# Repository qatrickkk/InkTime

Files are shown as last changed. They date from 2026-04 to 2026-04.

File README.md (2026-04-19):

# InkTime Smartwatch

InkTime is a custom, open source smartwatch based on Nordic nRF52840, designed to have a low power consumption. It features an E-Ink display, 3-axis accelerometer, haptic feedback, and a 3 button navigation system.

## System Architecture Diagram
```mermaid
flowchart LR
    subgraph PWR["Power Subsystem"]
        USB["USB-C"]
        CHG["BQ25180<br/>Li-Ion Charger / Power Path"]
        BAT["AKY0106<br/>Li-Po Battery"]
        FG["MAX17048<br/>Fuel Gauge"]
        REG["RT6160<br/>Buck-Boost 3.3 V"]
        EPDPWR["E-Paper Drive Circuit<br/>(boost / gate / HV rails)"]
    end

    subgraph CTRL["Main Control"]
        MCU["nRF52840"]
    end

    subgraph PERI["Peripherals"]
        EPD["WSH-12561<br/>E-Ink Display"]
        IMU["BMA423 IMU"]
        HAPTIC["DRV2605<br/>Haptic Driver"]
        MOTOR["FIT0774<br/>Vibration Motor"]
        BTN["3 Physical Buttons<br/>(UP / ENTER / DOWN)"]
    end

    USB -->|VBUS| CHG
    BAT <-->|VBAT| CHG
    BAT -->|Cell voltage| FG
    CHG -->|SYS / VREG| REG
    REG -->|3V3| MCU
    REG -->|3V3| IMU
    REG -->|3V3| FG
    REG -->|3V3| HAPTIC
    REG -->|3V3| EPDPWR
    EPDPWR -->|EPD_3V3 + PREVGH / PREVGL| EPD

    MCU <-->|I2C| IMU
    MCU <-->|I2C| FG
    MCU <-->|I2C| HAPTIC
    MCU <-->|I2C| CHG
    MCU <-->|I2C| REG

    MCU -->|SPI SCK / MOSI| EPD
    MCU -->|GPIO: CS / DC / RST| EPD
    EPD -->|GPIO: BUSY| MCU

    MCU <-->|GPIO| BTN
    MCU -->|EN / TRIG| HAPTIC
    HAPTIC -->|OUT+ / OUT-| MOTOR
```

## Hardware Functionality
The nRF52840 is the central controller of the InkTime smartwatch. It runs the firmware, decides when to sleep and wake up, reads sensors, updates the display, handles the buttons, and manages communication with the other chips.

Around the MCU, there are five smaller systems that work together to create a fully functional smartwatch.

The power system is responsible for providing clean power used to charge and operate the watch.

- USB-C brings power from the charger,
- BQ25180 charges the battery and manages the power flow,
- AKY0106 is the battery itself,
- RT6160 generates the regulated 3.3 V rail,
- MAX17048 monitors the battery status and indicates how full it is.

The display system is the bridge between the internal data and the actual information the user sees. Unlike LCD or OLED panels, it does not need continuous power to hold an image, because the ink particles remain in the same position. Therefore, power is mainly used only when the image is changed or refreshed, making it well suited for this use case.

The motion system helps the smartwatch stay in a low-power state by using IMU data, allowing the watch to wake up only when a specific motion occurs, for example a tilt.

The haptic system is based on the DRV2605 haptic driver. Its role is to give the smartwatch user physical feedback through vibration, for example when a notification appears, an alarm is triggered, or a button press is confirmed.

The user input system is formed by three physical buttons: SW_UP, SW_ENT, and SW_DW. These buttons allow the user to interact with the smartwatch in a simple and reliable way.

Power Profile Estimate
- the nRF52840 stays in deep sleep most of the time, below 10 µA,
- the watch wakes once per minute,
- the E-Ink display is refreshed for about 1–2 s,
- active current during refresh is around 8–10 mA.

## nRF52840 Pin Allocation
| Peripheral | Pin(s) | Function | Justification |
| --- | --- | --- | --- |
| SPI SCK | P0.02 | Clock | SPI clock for the E-Ink display. |
| SPI MOSI | P0.03 | Data | Sends pixel data to the E-Ink display. |
| EPD CS | P0.05 | Chip Select  | Selects the display on the SPI bus. |
| I2C SDA | P0.06 | Data | Shared data line for sensors and power ICs. |
| I2C SCL | P0.07 | Clock | Shared clock line for the I2C bus. |
| IMU INT1 | P0.08 | Interrupt | Main interrupt from the IMU. |
| Fuel Gauge ALERT | P0.09 | Interrupt | Battery alert signal from MAX17048. |
| PMIC INT | P0.11 | Interrupt | Status or fault signal from BQ25180. |
| HAPTIC_EN | P0.12 | Control | Controls the haptic driver. |
| Button UP | P0.13 | GPIO Input | Reads the UP button state. |
| Button ENTER | P0.14 | GPIO Input | Reads the ENTER button state. |
| EPD DC | P0.15 | Control | Selects command or data mode for the display. |
| EPD RST | P0.16 | Control | Resets the E-Ink display. |
| EPD BUSY | P0.17 | Status Input | Shows when the display is busy refreshing. |
| nRESET | P0.18 / RESET | Reset | Resets the MCU. |
| Button DOWN | P1.02 | GPIO Input | Reads the DOWN button state. |
| IMU INT2 | P1.08 | Interrupt | Secondary interrupt from the IMU. |
| USB D+ | D+ | USB Data | USB communication line. |
| USB D- | D- | USB Data | USB communication line. |
| SWDIO | SWDIO | Debug | Debug and programming data line. |
| SWDCLK | SWDCLK | Debug | Debug and programming clock line. |

## Bill of Materials (BOM)
| Qty | Value | Parts | Device | Package | Product Link | Datasheet Link |
| --: | --- | --- | --- | --- | --- | --- |
| 1 | nRF52840-QIAA | U1 | NORDIC_NRF_4_NRF52840_QF | AQFN-73-EP(7x7) | [JLCPCB](https://jlcpcb.com/partdetail/NordicSemicon-NRF52840_QIAAR/C190794) | [Datasheet](https://infocenter.nordicsemi.com/pdf/nRF52840_PS_v1.9.pdf) |
| 1 | BQ25180YBGR | IC1 | BQ25180YBGR | DSBGA-8(1.1x1.6) | [JLCPCB](https://jlcpcb.com/partdetail/TexasInstruments-BQ25180YBGR/C3682423) | [Datasheet](https://www.ti.com/lit/ds/symlink/bq25180.pdf) |
| 1 | MAX17048G+T10 | U3 | ESP32_C6_LIBRARY_MAX17048G+T10 | DFN-8-EP(2x2) | [JLCPCB](https://jlcpcb.com/partdetail/MaximIntegrated-MAX17048GT10/C2682616) | [Datasheet](https://www.analog.com/media/en/technical-documentation/data-sheets/MAX17048-MAX17049.pdf) |
| 1 | DRV2605YZFR | IC2 | DRV2605YZFR | DSBGA-9 | [JLCPCB](https://jlcpcb.com/partdetail/TexasInstruments-DRV2605YZFR/C81079) | [Datasheet](https://www.ti.com/lit/ds/symlink/drv2605.pdf) |
| 1 | DMG2305UX-7 | P-channel MOSFET | DMG2305UX-7 | SOT-23 | [JLCPCB](https://jlcpcb.com/partdetail/HXYMOSFET-DMG2305UX7/C5261054) | [Datasheet](https://www.diodes.com/assets/Datasheets/DMG2305UX.pdf) |
| 1 | SI1308EDL-T1-GE3  | Q3 | ESP32_C6_LIBRARY_6_SI1308EDL-T1-GE3 | SOT-323 | [JLCPCB](https://jlcpcb.com/partdetail/TECHPUBLIC-SI1308EDL/C7603347) | [Datasheet](https://www.vishay.com/docs/63399/si1308edl.pdf) |
| 3 | MBR0530 | D2, D4, D5 | MBR0530 | SOD-123 | [JLCPCB](https://jlcpcb.com/partdetail/4324765-MBR0530_F20000HF/C3757235) | [Datasheet](https://wmsc.lcsc.com/wmsc/upload/file/pdf/v2/lcsc/2205311800_Yangzhou-Yangjie-Electronic-Technology-MBR0530-F2-0000HF_C3757235.pdf) |
| 1 | USBLC6-2SC6Y | D3 | USBLC6-2SC6Y | SOT-23-6 | [JLCPCB](https://jlcpcb.com/partdetail/TECHPUBLIC-USBLC62SC6Y/C5310974) | [Datasheet](https://wmsc.lcsc.com/wmsc/upload/file/pdf/v2/lcsc/2401261525_TECH-PUBLIC-USBLC6-2SC6Y_C5310974.pdf) |
| 1 | 2450AT18B100E | ANT1 | 2450AT18B100E_2450AT18B100E | ANTC3216X140N / 1206 class | [JLCPCB](https://jlcpcb.com/partdetail/JohansonTechnology-2450AT18B100/C2836414) | [Datasheet](https://www.johansontechnology.com/datasheets/antennas/2450AT18B100.pdf) |
| 1 | KH-TYPE-C-16P | J4 | KH-TYPE-C-16P_KH-TYPE-C-16P | SMD | [JLCPCB](https://jlcpcb.com/partdetail/KH-TYPE-C-16P/C709357) | [Datasheet](https://wmsc.lcsc.com/wmsc/upload/file/pdf/v2/lcsc/2204251630_SHENZHEN-KINGHELM-Elec-KH-TYPE-C-16P_C709357.pdf) |
| 3 | EVP-AKE31A | SW_DN, SW_ENT, SW_UP | EVP-AKE31A | SW_EVP-AKE31A_PAN | [JLCPCB](https://jlcpcb.com/partdetail/PANASONIC-EVPAKE31A/C569760) | [Datasheet](https://www.lcsc.com/datasheet/C569760.pdf) |
| 1 | FTC252012SR47MBCA | L7 | MLP2016SR47MT0S1_FTC252012SR47MBCA  | INDC2016X100N | [JLCPCB](https://jlcpcb.com/partdetail/6763488-FTC252012SR47MBCA/C5832368) | [Datasheet](https://wmsc.lcsc.com/wmsc/upload/file/pdf/v2/lcsc/2311271530_TDK-FTC252012SR47MBCA_C5832368.pdf) |
| 1 | 32.768 kHz | X2 | NORDIC_NRF_1_XTAL_32KHZ | SMD3215-2P | [JLCPCB](https://jlcpcb.com/partdetail/NDK-NX3215SA_32_768K_STD_MUA9/C519280) | [Datasheet](https://www.ndk.com/images/products/crystal/resonator/NX3215SA_e.pdf) |
| 6 | 10K | R2_EP_DR, R5, R7, R8, R9, R_PWR_EPD | RC0201FR-1310KL | 0201 | [JLCPCB](https://jlcpcb.com/partdetail/YAGEO-RC0201FR1310KL/C6373588) | [Datasheet](https://www.lcsc.com/datasheet/C6373588.pdf) |
| 2 | 5K1 | R1_USB, R2_USB | RC0201FR-075K1L | 0201 | [JLCPCB](https://jlcpcb.com/partdetail/YAGEO-RC0201FR075K1L/C274341) | [Datasheet](https://www.lcsc.com/datasheet/C274341.pdf) |
| 2 | 3K3 | R17, R18 | RNCF0201DTC3K30 | 0201 | [JLCPCB](https://jlcpcb.com/partdetail/SEI_Stackpole_Elec-RNCF0201DTC3K30/C2487997) | [Datasheet](https://www.lcsc.com/datasheet/C2487997.pdf) |
| 3 | 0R | R2, R3, R4 | 0201WMJ0000TCE | 0201 | [JLCPCB](https://jlcpcb.com/partdetail/25793-0201WMJ0000TCE/C25050) | [Datasheet](https://www.lcsc.com/datasheet/C25050.pdf) |
| 1 | 2.2Ω | R_TYPE_SEL | 0201WMF220KTCE | 0201 | [JLCPCB](https://jlcpcb.com/partdetail/244650-0201WMF220KTCE/C247442) | [Datasheet](https://www.lcsc.com/datasheet/C247442.pdf) |
| 9 | 100nF | C5, C7, C8, C12, C19, C23, C27, C34, C42 | AC0201KRX6S6BB104 | 0201 | [JLCPCB](https://jlcpcb.com/partdetail/YAGEO-AC0201KRX6S6BB104/C3855913) | [Datasheet](https://www.lcsc.com/datasheet/C3855913.pdf) |
| 4 | 12pF | C1, C2, C17, C18 | 0201N120J250CT | 0201 | [JLCPCB](https://jlcpcb.com/partdetail/Walsin_TechCorp-0201N120J250CT/C424835) | [Datasheet](https://www.lcsc.com/datasheet/C424835.pdf) |
| 2 | 1pF | C3, C4 | GRM0335C1E1R0CA01J | 0201 | [JLCPCB](https://jlcpcb.com/partdetail/2274979-GRM0335C1E1R0CA01J/C2182912) | [Datasheet](https://www.lcsc.com/datasheet/C2182912.pdf) |
| 1 | 100pF | C11 | 0201N101F160CT | 0201 | [JLCPCB](https://jlcpcb.com/partdetail/Walsin_TechCorp-0201N101F160CT/C3847857) | [Datasheet](https://www.lcsc.com/datasheet/C3847857.pdf) |
| 1 | 47nF | C16 | C0201X5R473K160NTA | 0201 | [JLCPCB](https://jlcpcb.com/partdetail/126083-C0201X5R473K160NTA/C124806) | [Datasheet](https://www.lcsc.com/datasheet/C124806.pdf) |
| 1 | 1uF | C15 | CL05A105KP5NNNC | 0402 | [JLCPCB](https://jlcpcb.com/partdetail/C14445) | [Datasheet](https://www.lcsc.com/datasheet/C14445.pdf) |
| 5 | 4.7uF | C6, C14, C20, C21, C43 | GRM155R61A475KEAAD | 0402 | [JLCPCB](https://jlcpcb.com/partdetail/MurataElectronics-GRM155R61A475KEAAD/C77004) | [Datasheet](https://www.lcsc.com/datasheet/C77004.pdf) |
| 1 | 4.7uF / 25V | C2-EP-DR | C0402X5R475M250NT | 0402 | [JLCPCB](https://jlcpcb.com/partdetail/SANYEAR-C0402X5R475M250NT/C2911388) | [Datasheet](https://www.lcsc.com/datasheet/C2911388.pdf) |
| 9 | 1uF / 50V | EPD_C1, EPD_C2, EPD_C6, EPD_C7, EPD_C8, EPD_C9, EPD_C10, EPD_C11, EPD_C12 | GRM155R61H105KE05D | 0402 | [JLCPCB](https://jlcpcb.com/partdetail/1609005-GRM155R61H105KE05D/C1518208) | [Datasheet](https://www.lcsc.com/datasheet/C1518208.pdf) |
| 2 | 10uF | C24, C39 | 0402X106M100CT | 0402 | [JLCPCB](https://jlcpcb.com/partdetail/Walsin_TechCorp-0402X106M100CT/C2992625) | [Datasheet](https://www.lcsc.com/datasheet/C2992625.pdf) |
| 2 | 22uF | C25, C33 | CL05A226MQ6ZUN8 | 0402 | [JLCPCB](https://jlcpcb.com/partdetail/2889851-CL05A226MQ6ZUN8/C2762589) | [Datasheet](https://www.lcsc.com/datasheet/C2762589.pdf) |
| 1 | 820pF | C9 | MA0201XF821K250 | 0201 | [JLCPCB](https://jlcpcb.com/partdetail/Meritek-MA0201XF821K250/C3842403) | [Datasheet](https://www.lcsc.com/datasheet/C3842403.pdf) |
| 1 | 32MHz | X1 | NX2016SA-32MHZ-STD-CZS-5 | SMD2016-4P | [JLCPCB](https://jlcpcb.com/partdetail/NDK-NX2016SA_32MHZ_STD_CZS5/C843260) | [Datasheet](https://www.lcsc.com/datasheet/C843260.pdf) |
| 1 | 3.9nH | L1 | VHF060303H3N9ST | 0201 | [JLCPCB](https://jlcpcb.com/partdetail/153834-VHF060303H3N9ST/C142503) | [Datasheet](https://www.lcsc.com/datasheet/C142503.pdf) |
| 1 | 15nH | L3 | MLK0603L15NJT000 | 0201 | [JLCPCB](https://jlcpcb.com/partdetail/TDK-MLK0603L15NJT000/C6990407) | [Datasheet](https://www.lcsc.com/datasheet/C6990407.pdf) |
| 1 | BMA421 | IC3 | BMA421 | LGA-12(2x2) | [JLCPCB](https://jlcpcb.com/partdetail/BoschSensortec-BMA421/C5242966) | [Datasheet](https://files.pine64.org/doc/datasheet/pinetime/BST-BMA421-FL000.pdf) |
| 1 | RT6160AWSC | IC9 | RT6160AWSC | WLCSP-15B(2.3x1.4) | [JLCPCB](https://jlcpcb.com/partdetail/RichtekTech-RT6160AWSC/C7065276) | [Datasheet](https://www.mouser.com/datasheet/2/1458/DS6160A_03-3104604.pdf) |
| 1 | 503480-2400 | J1 | 5034802400 | 24-pin 0.5mm right-angle FPC | [JLCPCB](https://jlcpcb.com/partdetail/MOLEX-5034802400/C122434) | [Datasheet](https://www.mouser.com/datasheet/2/276/2/5034802400_FFC_FPC_CONNECTORS-1112921.pdf) |

## Mechanical Design Log
The following design decisions were made during the hardware development process in order to meet the mechanical and electrical constraints of the project:

* **Board thickness:** The PCB was designed with a thickness of **1 mm** to match the enclosure dimensions. All components were placed on the **TOP layer**.
* **Antenna design:** The antenna was placed on the outer edge of the PCB. The area below the antenna was kept free of traces and ground copper to preserve RF performance. Via stitching was also added between the ground planes around the radio section.
* **Routing rules:** Power traces were routed with a width of **0.3 mm**, while data traces were routed with a minimum width of **0.15 mm**. The **100 nF decoupling capacitors** were placed as close as possible to the power pins of the ICs. For some BGA devices and for the MCU, **0.15 mm power traces** were also used locally to allow proper fanout from the pins.
* **Enclosure adjustments:** The case was modified by a few millimeters where needed so that all parts could fit correctly and to avoid overlap errors. The main changes were made to provide enough clearance for the **display** and the **battery** inside the enclosure.
* **BGA / MCU vias:** For BGA-type components and for the MCU, **via-in-pad style escape routing** was used in some areas, with **0.15 mm / 0.2 mm** via dimensions, as allowed by the course requirements.
* **Accepted errors:** The DRC **“Dimension”** errors related to the three buttons and the USB connector were intentionally accepted, since their placement was dictated by the mechanical alignment with the enclosure cutouts. The **“Only INPUT pins on NET ID”** error was also ignored, since it is an accepted behavior in this project context.

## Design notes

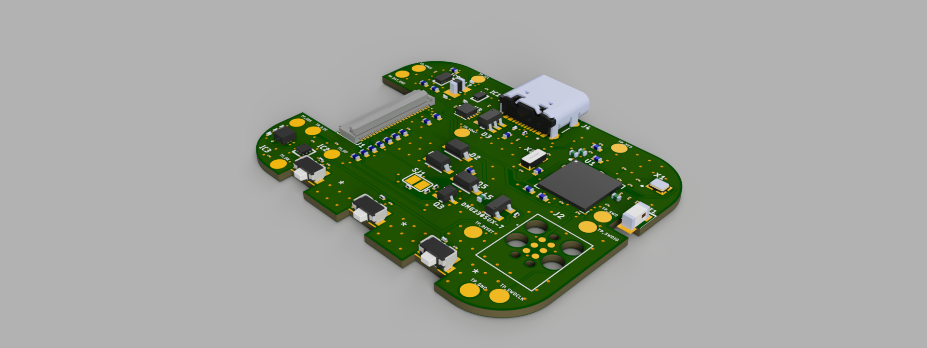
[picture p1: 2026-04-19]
Images/PCB_3D_side.png

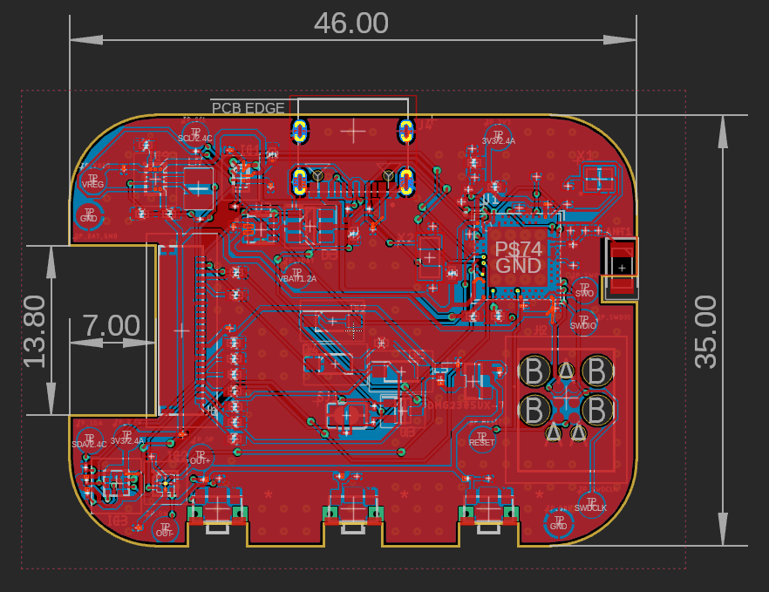
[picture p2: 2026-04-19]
Images/PCB_2D.png

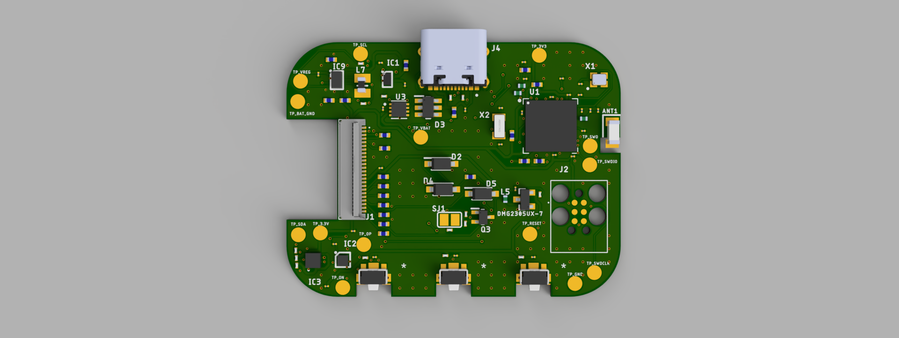
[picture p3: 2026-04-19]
Images/PCB_3D_top.png

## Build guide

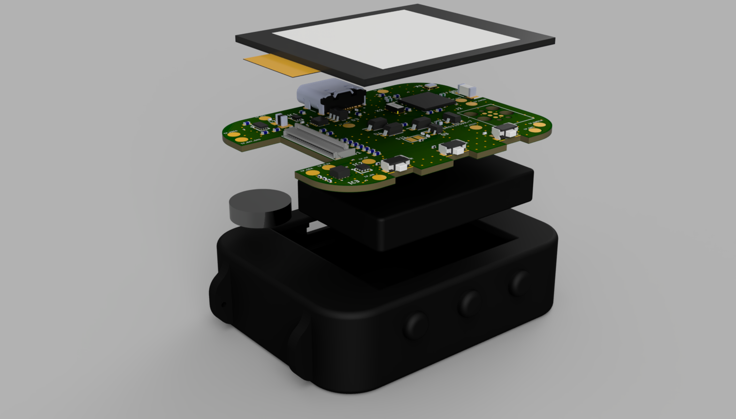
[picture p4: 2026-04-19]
Images/Assembly_Exploded.png

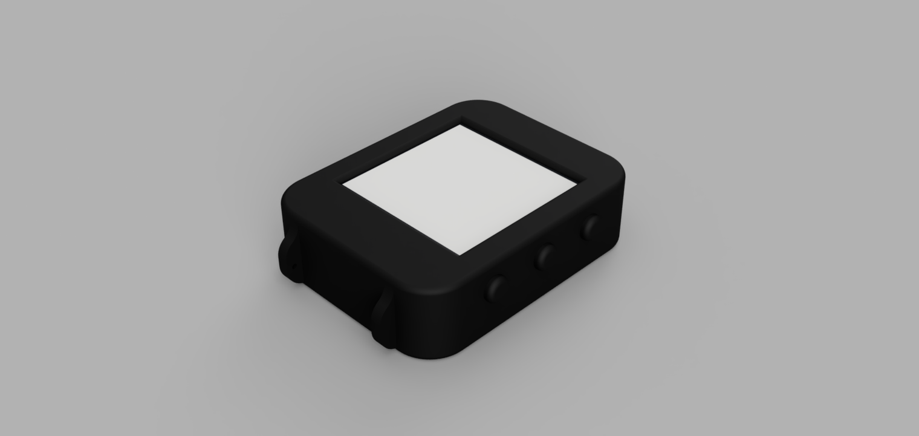
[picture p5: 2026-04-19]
Images/Assembly.png

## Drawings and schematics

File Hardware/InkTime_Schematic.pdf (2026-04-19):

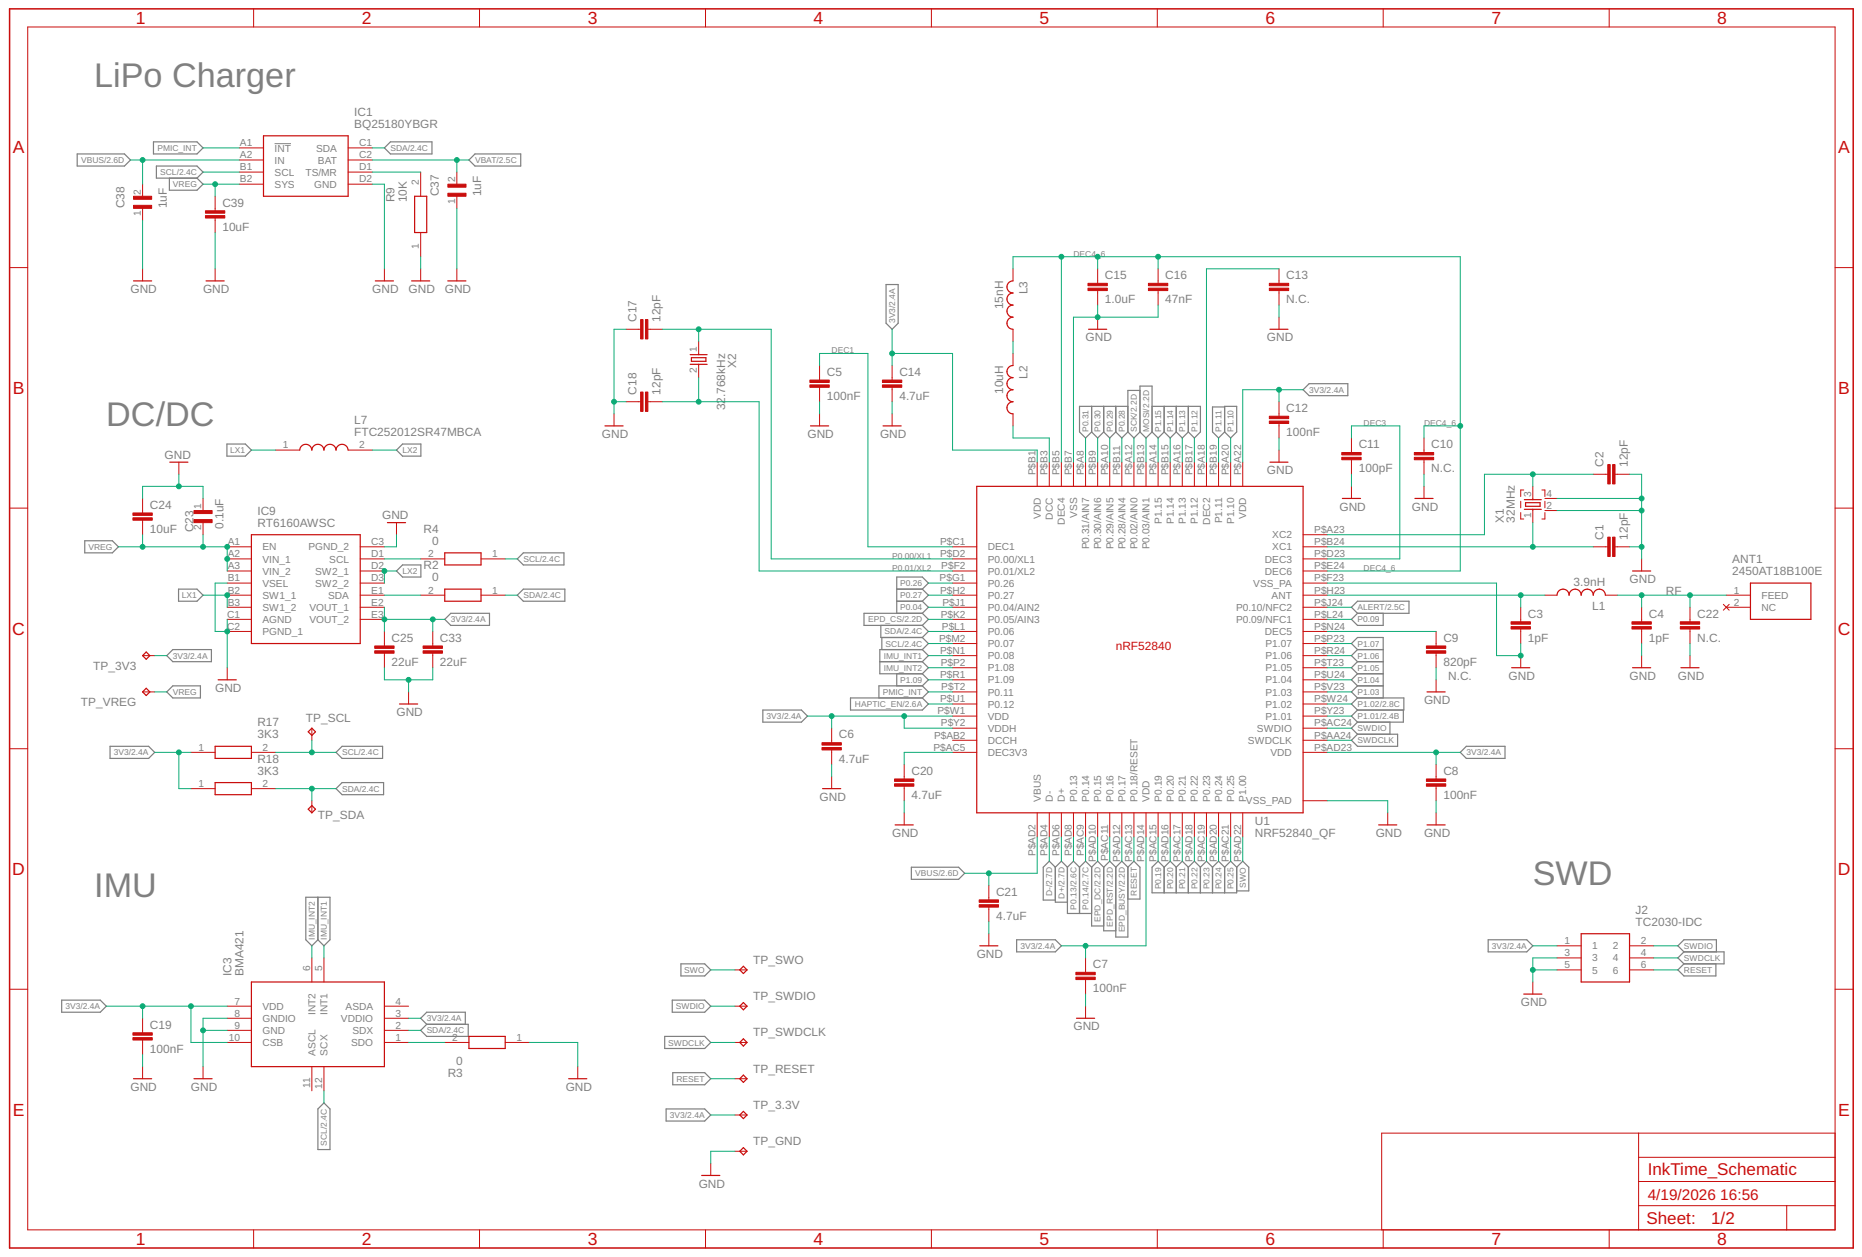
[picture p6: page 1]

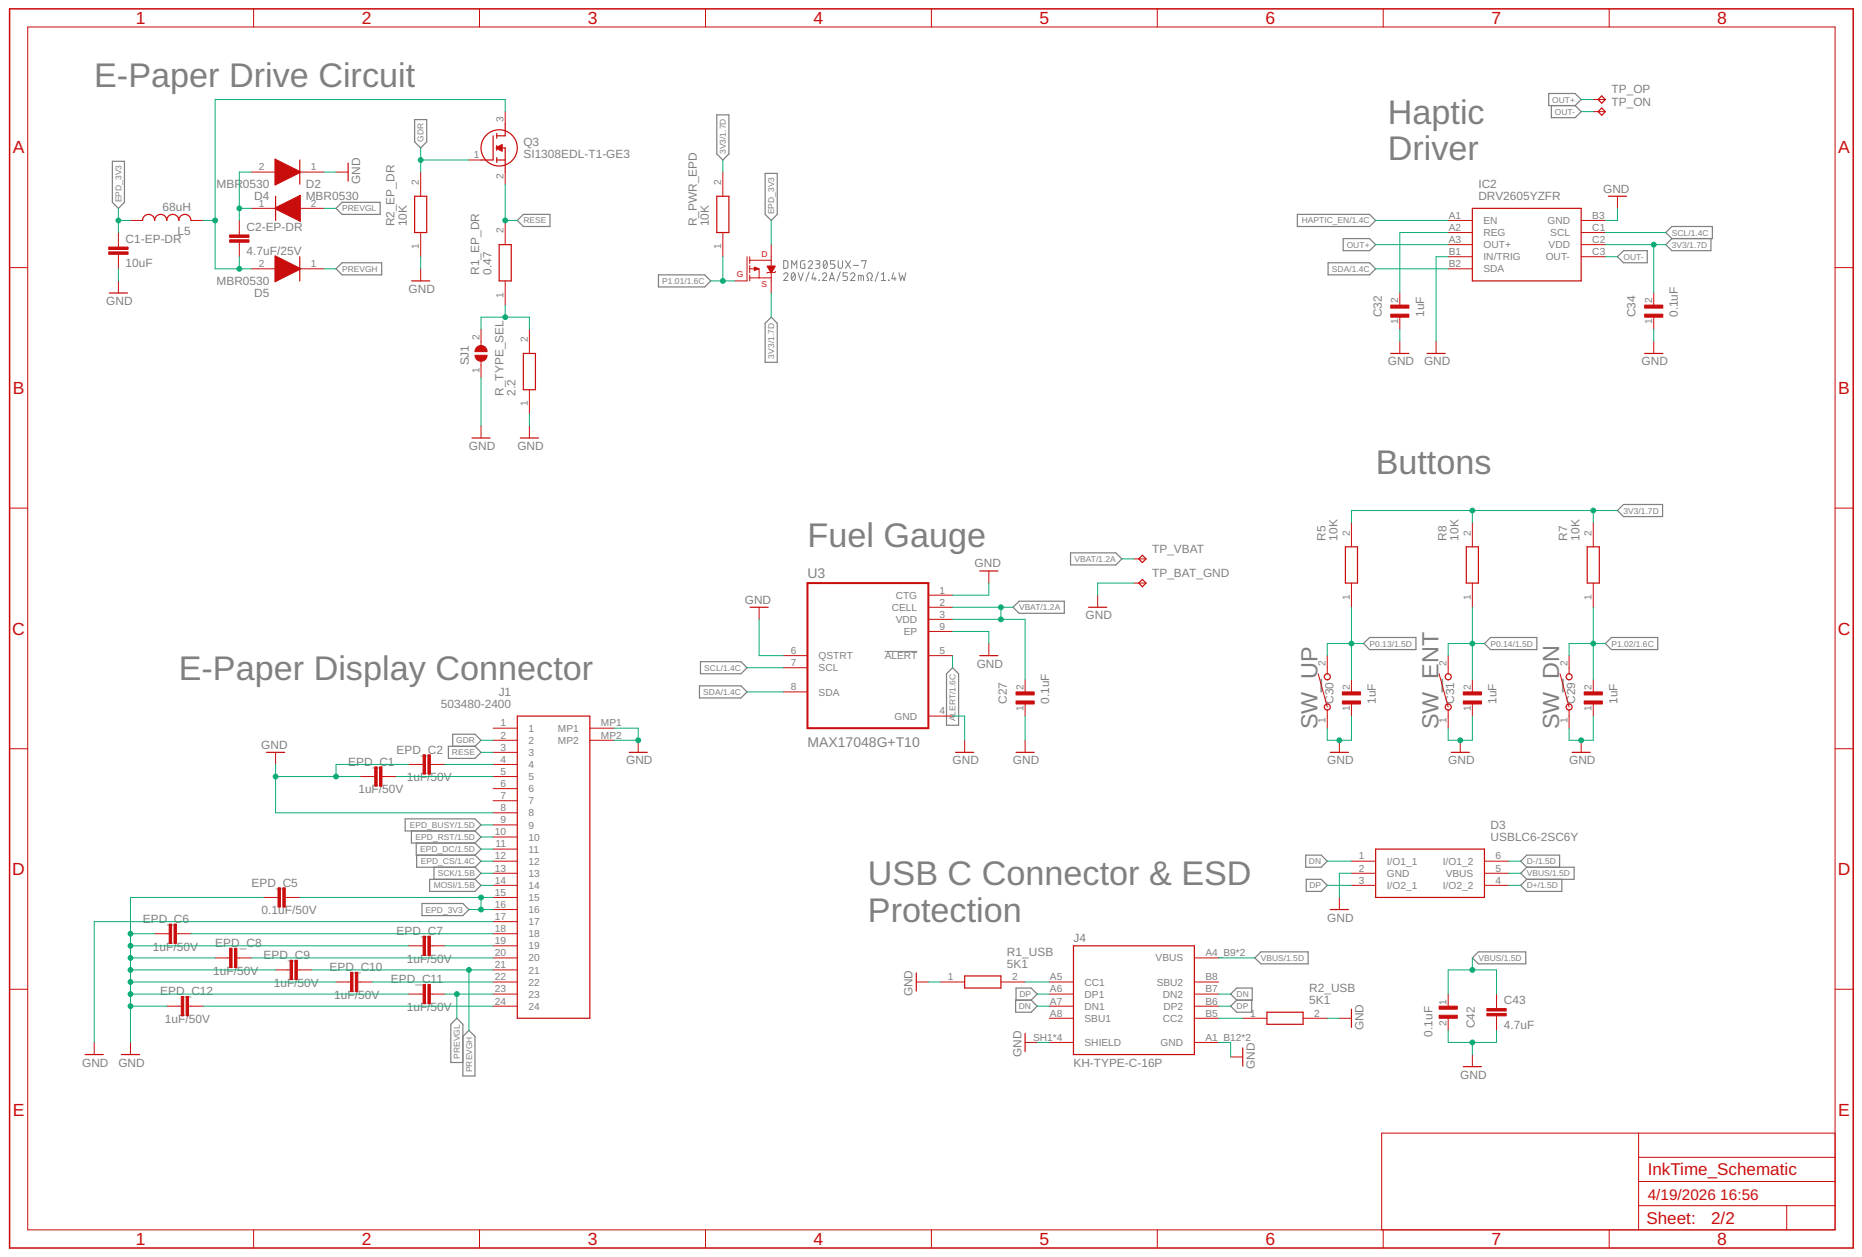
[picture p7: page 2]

EPD_C7 18

EPD_C8 | 19

EPD_C11 | 22

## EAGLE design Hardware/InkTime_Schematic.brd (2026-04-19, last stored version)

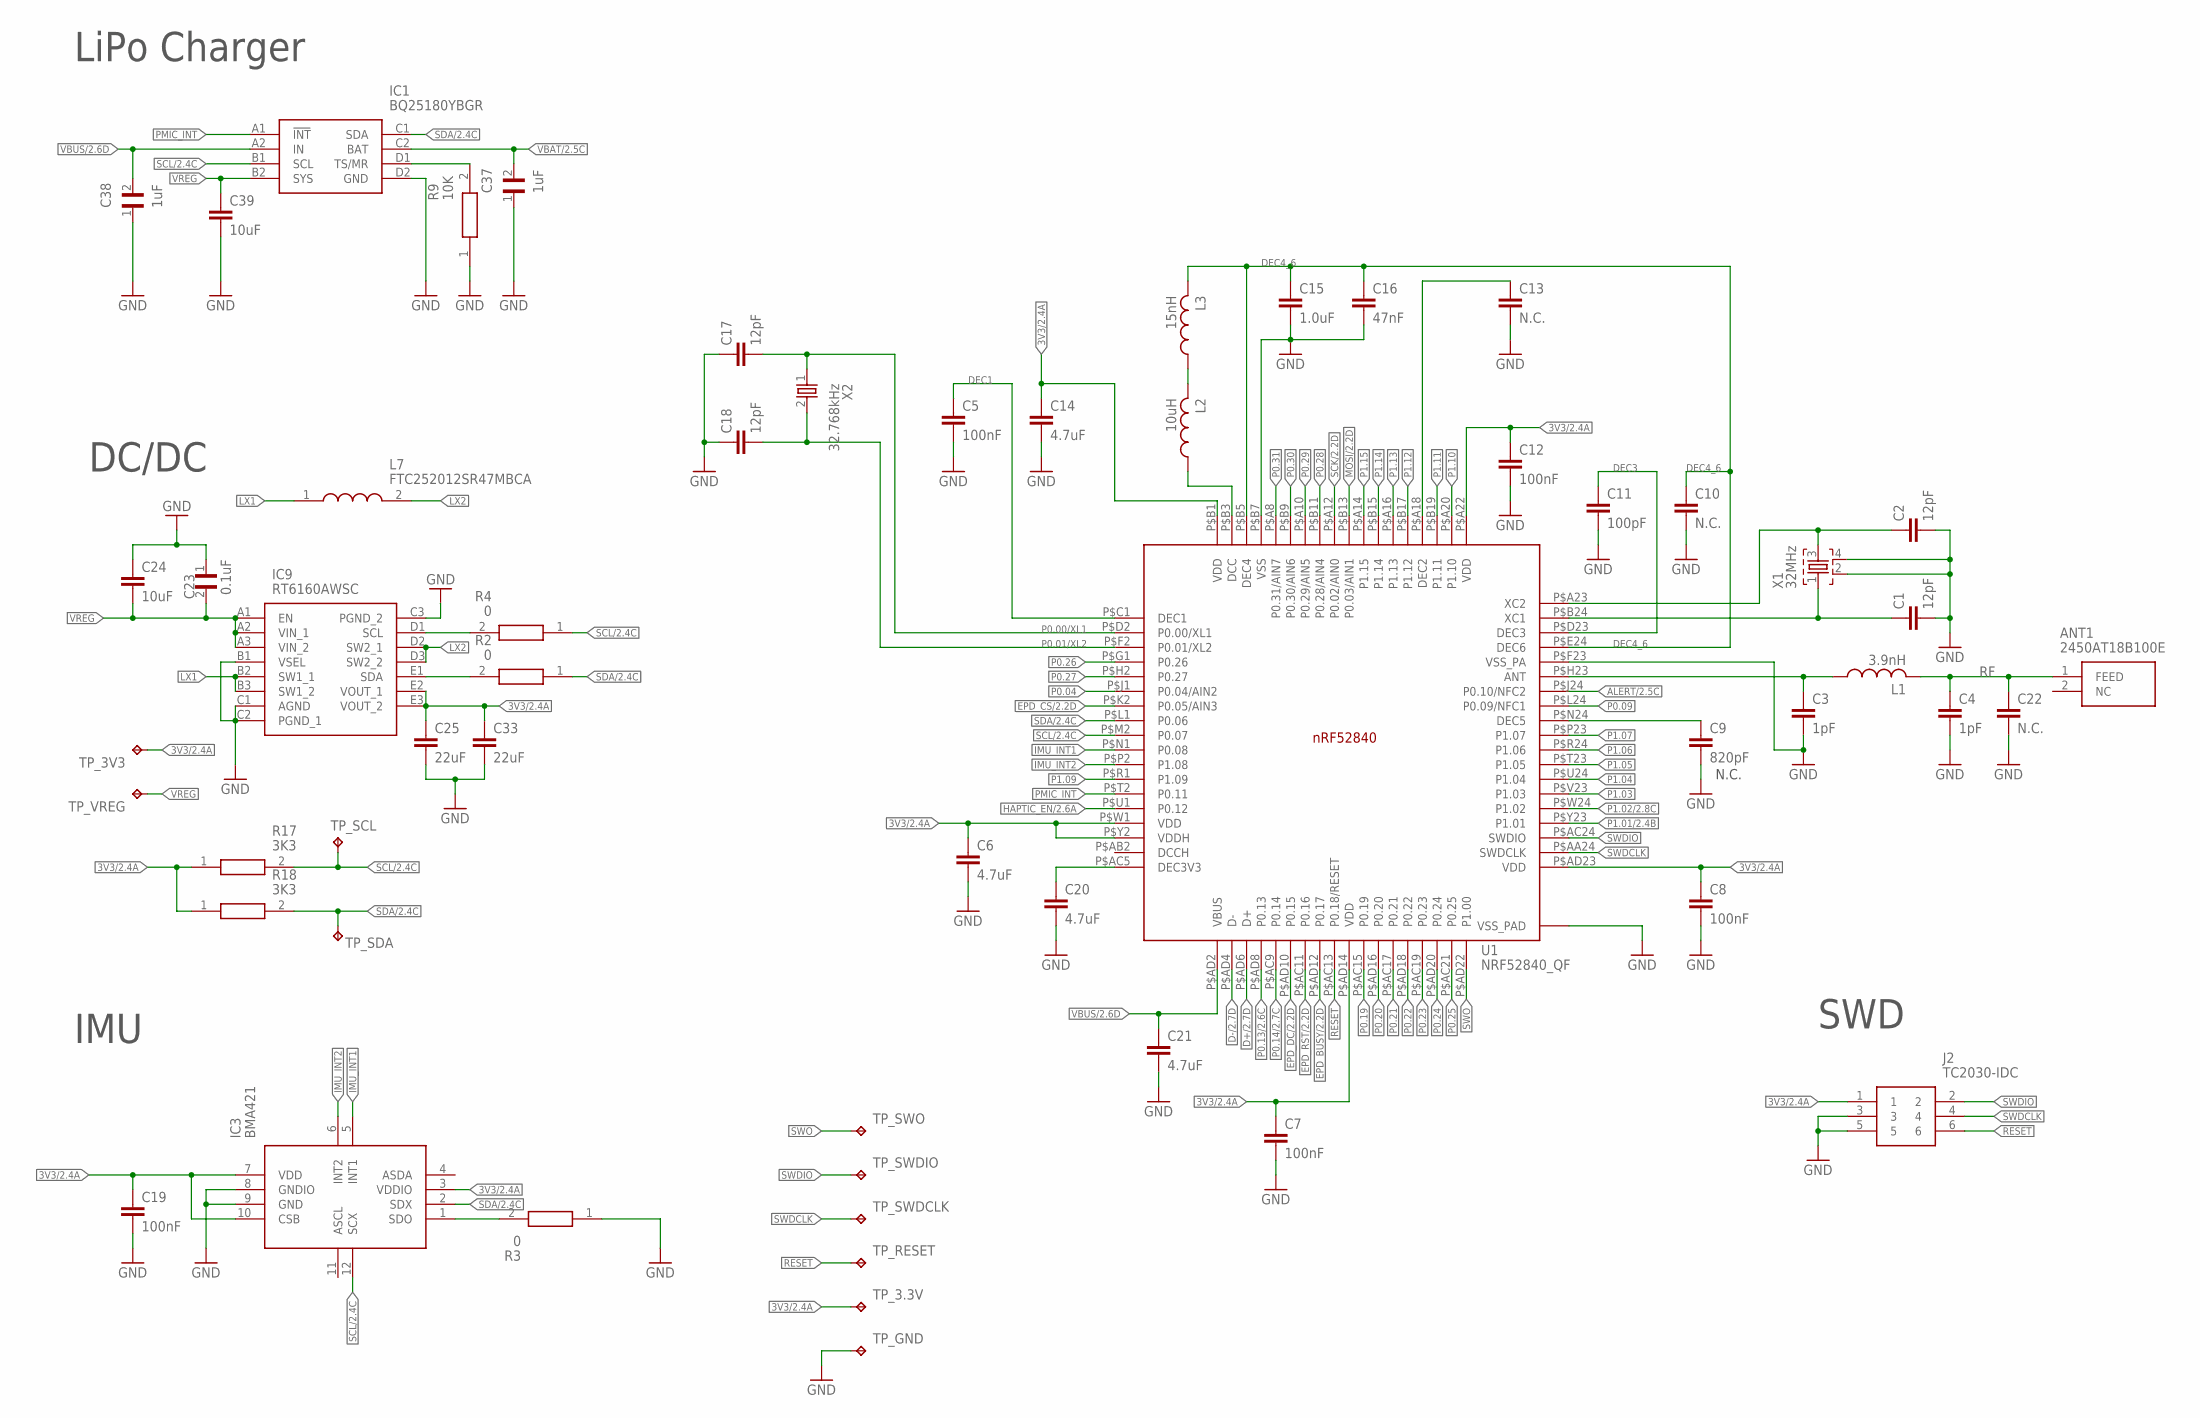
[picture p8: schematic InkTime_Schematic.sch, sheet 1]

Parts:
ANT1: 2450AT18B100E; 2450AT18B100E_ANTC3216X140N
C1, C2, C17, C18: 12pF; GRM011R60J152KE01L_2_CAPC0201X13N
C3, C4: 1pF; GRM011R60J152KE01L_2_CAPC0201X13N
C5, C7, C8, C12, C19: 100nF; GRM011R60J152KE01L_2_CAPC0201X13N
C6, C14, C20, C21: 4.7uF; NORDIC_NRF_3_RESC0402_L
C9: 820pF; GRM011R60J152KE01L_2_CAPC0201X13N
C10, C13, C22: N.C.; GRM011R60J152KE01L_2_CAPC0201X13N
C11: 100pF; GRM011R60J152KE01L_2_CAPC0201X13N
C15: 1.0uF; NORDIC_NRF_3_RESC0402_L
C16: 47nF; GRM011R60J152KE01L_2_CAPC0201X13N
C23: 0.1uF; GRM011R60J152KE01L_2_CAPC0201X13N
C24, C39: 10uF; NORDIC_NRF_3_RESC0402_L
C25, C33: 22uF; NORDIC_NRF_3_RESC0402_L
C37, C38: 1uF; GRM011R60J152KE01L_2_CAPC0201X13N
IC1: BQ25180YBGR; BQ25180YBGR_BGA8C40P2X4_100X155X50
IC3: BMA421; BMA423_BMA423
IC9: RT6160AWSC; RT6160AWSC_BGA15C40P3X5_140X230X60
J2: TC2030-IDC; TC2030-IDC_TC2030IDC
L1: 3.9nH; NORDIC_NRF_2_RESC0201_L
L2: 10uH; NORDIC_NRF_2_RESC0201_L
L3: 15nH; NORDIC_NRF_2_RESC0201_L
L7: FTC252012SR47MBCA; MLP2016SR47MT0S1_INDC2016X100N
R2, R3, R4: 0; CPF0201D7K68C1_0201
R9: 10K; CPF0201D7K68C1_0201
R17, R18: 3K3; CPF0201D7K68C1_0201
TP_3.3V, TP_3V3: HECTOR_WATCH_1_TPTP20R; HECTOR_WATCH_1_TP20R
TP_GND: HECTOR_WATCH_1_TPTP20R; HECTOR_WATCH_1_TP20R
TP_RESET: HECTOR_WATCH_1_TPTP20R; HECTOR_WATCH_1_TP20R
TP_SCL: HECTOR_WATCH_1_TPTP20R; HECTOR_WATCH_1_TP20R
TP_SDA: HECTOR_WATCH_1_TPTP20R; HECTOR_WATCH_1_TP20R
TP_SWDCLK: HECTOR_WATCH_1_TPTP20R; HECTOR_WATCH_1_TP20R
TP_SWDIO: HECTOR_WATCH_1_TPTP20R; HECTOR_WATCH_1_TP20R
TP_SWO: HECTOR_WATCH_1_TPTP20R; HECTOR_WATCH_1_TP20R
TP_VREG: HECTOR_WATCH_1_TPTP20R; HECTOR_WATCH_1_TP20R
U1: NRF52840_QF; NORDIC_NRF_4_AQFN50P700X700X85_HS-74N
X1: 32MHz; NORDIC_NRF_BT-XTAL_2016_N
X2: 32.768kHz; NORDIC_NRF_1_XTAL_3215_N

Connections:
3V3/2.4A: C6.1, C7.1, C8.1, C12.1, C14.1, C19.1, C25.1, C33.1, IC3.3 (VDDIO), IC3.7 (VDD), IC3.10 (CSB), IC9.E2 (VOUT_1), IC9.E3 (VOUT_2), J2.1, R17.1, R18.1, TP_3.3V.TP, TP_3V3.TP, U1.P$A22 (VDD), U1.P$AD14 (VDD), U1.P$AD23 (VDD), U1.P$B1 (VDD), U1.P$W1 (VDD), U1.P$Y2 (VDDH)
ALERT/2.5C: U1.P$J24 (P0.10/NFC2)
D+/2.7D: U1.P$AD6 (D+)
D-/2.7D: U1.P$AD4 (D-)
DEC1: C5.1, U1.P$C1 (DEC1)
DEC3: C11.1, U1.P$D23 (DEC3)
DEC4_6: C10.1, C15.1, C16.1, L3.2, U1.P$B5 (DEC4), U1.P$E24 (DEC6)
EPD_BUSY/2.2D: U1.P$AD12 (P0.17)
EPD_CS/2.2D: U1.P$K2 (P0.05/AIN3)
EPD_DC/2.2D: U1.P$AD10 (P0.15)
EPD_RST/2.2D: U1.P$AC11 (P0.16)
GND: C1.2, C2.2, C3.2, C4.2, C5.2, C6.2, C7.2, C8.2, C9.2, C10.2, C11.2, C12.2, C13.2, C14.2, C15.2, C16.2, C17.1, C18.1, C19.2, C20.2, C21.2, C22.2, C23.1, C24.1, C25.2, C33.2, C37.1, C38.1, C39.2, IC1.D2 (GND), IC3.8 (GNDIO), IC3.9 (GND), IC9.B1 (VSEL), IC9.C1 (AGND), IC9.C2 (PGND_1), IC9.C3 (PGND_2), J2.3, J2.5, R3.1, R9.1, TP_GND.TP, U1.P$74 (VSS_PAD), U1.P$75 (VSS_PAD), U1.P$76 (VSS_PAD), U1.P$77 (VSS_PAD), U1.P$78 (VSS_PAD), U1.P$79 (VSS_PAD), U1.P$80 (VSS_PAD), U1.P$81 (VSS_PAD), U1.P$82 (VSS_PAD), U1.P$83 (VSS_PAD), U1.P$84 (VSS_PAD), U1.P$85 (VSS_PAD), U1.P$86 (VSS_PAD), U1.P$87 (VSS_PAD), U1.P$88 (VSS_PAD), U1.P$89 (VSS_PAD), U1.P$90 (VSS_PAD), U1.P$B7 (VSS), U1.P$F23 (VSS_PA), X1.2, X1.4; also elsewhere on the board
HAPTIC_EN/2.6A: U1.P$U1 (P0.12)
IMU_INT1: IC3.5 (INT1), U1.P$N1 (P0.08)
IMU_INT2: IC3.6 (INT2), U1.P$P2 (P1.08)
LX1: IC9.B2 (SW1_1), IC9.B3 (SW1_2), L7.1
LX2: IC9.D2 (SW2_1), IC9.D3 (SW2_2), L7.2
MOSI/2.2D: U1.P$B13 (P0.03/AIN1)
unnamed: IC1.D1 (TS/MR), R9.2
unnamed: C2.1, U1.P$A23 (XC2), X1.3
unnamed: C1.1, U1.P$B24 (XC1), X1.1
unnamed: C3.1, L1.1, U1.P$H23 (ANT)
unnamed: IC3.1 (SDO), R3.2
unnamed: IC9.E1 (SDA), R2.2
unnamed: C9.1, U1.P$N24 (DEC5)
unnamed: IC9.D1 (SCL), R4.2
unnamed: L2.1, U1.P$B3 (DCC)
unnamed: L2.2, L3.1
unnamed: C13.1, U1.P$A18 (DEC2)
unnamed: C20.1, U1.P$AC5 (DEC3V3)
P0.00/XL1: C17.2, U1.P$D2 (P0.00/XL1), X2.1
P0.01/XL2: C18.2, U1.P$F2 (P0.01/XL2), X2.2
P0.04: U1.P$J1 (P0.04/AIN2)
P0.09: U1.P$L24 (P0.09/NFC1)
P0.13/2.6C: U1.P$AD8 (P0.13)
P0.14/2.7C: U1.P$AC9 (P0.14)
P0.19: U1.P$AC15 (P0.19)
P0.20: U1.P$AD16 (P0.20)
P0.21: U1.P$AC17 (P0.21)
P0.22: U1.P$AD18 (P0.22)
P0.23: U1.P$AC19 (P0.23)
P0.24: U1.P$AD20 (P0.24)
P0.25: U1.P$AC21 (P0.25)
P0.26: U1.P$G1 (P0.26)
P0.27: U1.P$H2 (P0.27)
P0.28: U1.P$B11 (P0.28/AIN4)
P0.29: U1.P$A10 (P0.29/AIN5)
P0.30: U1.P$B9 (P0.30/AIN6)
P0.31: U1.P$A8 (P0.31/AIN7)
P1.01/2.4B: U1.P$Y23 (P1.01)
P1.02/2.8C: U1.P$W24 (P1.02)
P1.03: U1.P$V23 (P1.03)
P1.04: U1.P$U24 (P1.04)
P1.05: U1.P$T23 (P1.05)
P1.06: U1.P$R24 (P1.06)
P1.07: U1.P$P23 (P1.07)
P1.09: U1.P$R1 (P1.09)
P1.10: U1.P$A20 (P1.10)
P1.11: U1.P$B19 (P1.11)
P1.12: U1.P$B17 (P1.12)
P1.13: U1.P$A16 (P1.13)
P1.14: U1.P$B15 (P1.14)
P1.15: U1.P$A14 (P1.15)
PMIC_INT: IC1.A1 (!INT), U1.P$T2 (P0.11)
RESET: J2.6, TP_RESET.TP, U1.P$AC13 (P0.18/RESET)
RF: ANT1.1 (FEED), C4.1, C22.1, L1.2
SCK/2.2D: U1.P$A12 (P0.02/AIN0)
SCL/2.4C: IC1.B1 (SCL), IC3.12 (SCX), R4.1, R17.2, TP_SCL.TP, U1.P$M2 (P0.07)
SDA/2.4C: IC1.C1 (SDA), IC3.2 (SDX), R2.1, R18.2, TP_SDA.TP, U1.P$L1 (P0.06)
SWDCLK: J2.4, TP_SWDCLK.TP, U1.P$AA24 (SWDCLK)
SWDIO: J2.2, TP_SWDIO.TP, U1.P$AC24 (SWDIO)
SWO: TP_SWO.TP, U1.P$AD22 (P1.00)
VBAT/2.5C: C37.2, IC1.C2 (BAT)
VBUS/2.6D: C21.1, C38.2, IC1.A2 (IN), U1.P$AD2 (VBUS)
VREG: C23.2, C24.2, C39.1, IC1.B2 (SYS), IC9.A1 (EN), IC9.A2 (VIN_1), IC9.A3 (VIN_2), TP_VREG.TP

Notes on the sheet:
LiPo Charger
DC/DC
IMU
SWD
N.C.

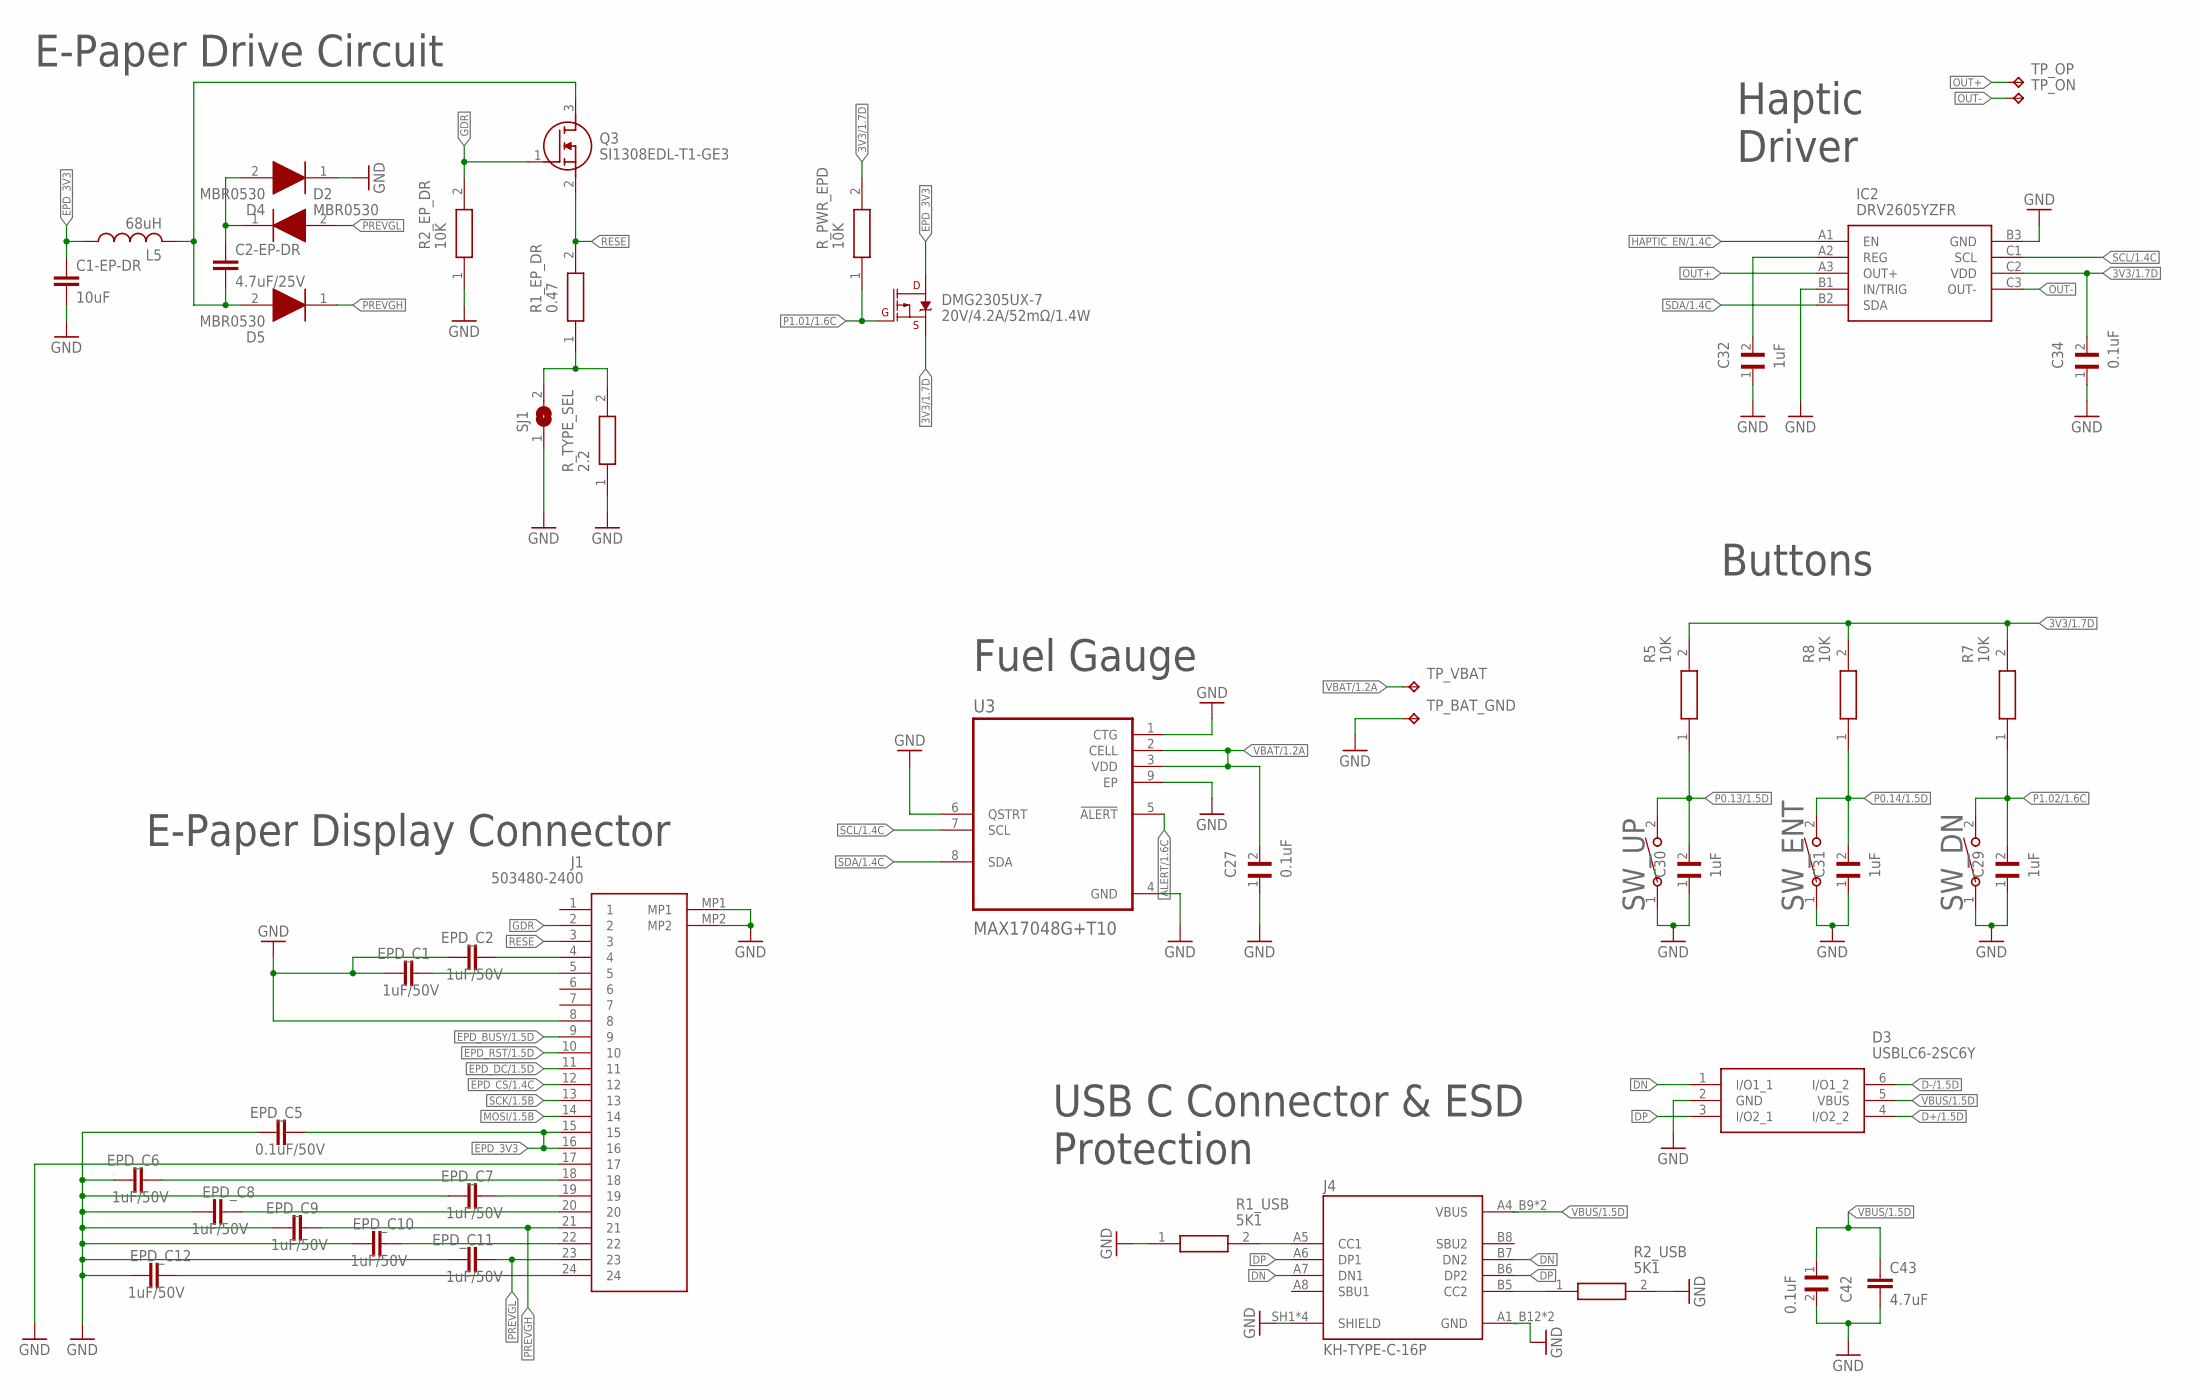
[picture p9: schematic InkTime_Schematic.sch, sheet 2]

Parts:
C1-EP-DR: 10uF; GRM011R60J152KE01L_2_CAPC0201X13N
C2-EP-DR: 4.7uF/25V; NORDIC_NRF_3_RESC0402_L
C27, C34, C42: 0.1uF; GRM011R60J152KE01L_2_CAPC0201X13N
C29, C30, C31, C32: 1uF; GRM011R60J152KE01L_2_CAPC0201X13N
C43: 4.7uF; NORDIC_NRF_3_RESC0402_L
D2, D4, D5: MBR0530; ESP32_C6_LIBRARY_5_SOD3716X135N
D3: USBLC6-2SC6Y; ESP32_C6_LIBRARY_3_SOT95P280X145-6N
DMG2305UX-7: 20V/4.2A/52mΩ/1.4W; ESP32_C6_LIBRARY_4_ESP32_C6_LIBRARY_4_ESP32_C6_LIBRARY_4_ES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
EPD_C1, EPD_C2, EPD_C6, EPD_C7, EPD_C8, EPD_C9, EPD_C10, EPD_C11, EPD_C12: 1uF/50V; NORDIC_NRF_3_RESC0402_L
EPD_C5: 0.1uF/50V; GRM011R60J152KE01L_2_CAPC0201X13N
IC2: DRV2605YZFR; DRV2605YZFR_BGA9C50P3X3_144X144X62
J1: 503480-2400; 503480-2400_5034802400
J4: KH-TYPE-C-16P; KH-TYPE-C-16P_KINGHELM_KH-TYPE-C-16P
L5: 68uH; NORDIC_NRF_2_RESC0201_L
Q3: SI1308EDL-T1-GE3; ESP32_C6_LIBRARY_6_SOT65P210X110-3N
R1_EP_DR: 0.47; CPF0201D7K68C1_0201
R1_USB, R2_USB: 5K1; CPF0201D7K68C1_0201
R2_EP_DR, R5, R7, R8: 10K; CPF0201D7K68C1_0201
R_PWR_EPD: 10K; CPF0201D7K68C1_0201
R_TYPE_SEL: 2.2; CPF0201D7K68C1_0201
SJ1: ESP32_C6_LIBRARY_7_JUMPER_SJ
SW_DN: 2025-10-22_07-23-44_LIBRARY_EVP-AKE31ASW_EVP-AKE3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; 2025-10-22_07-23-44_LIBRARY_SW_EVP-AKE31A_PAN
SW_ENT: 2025-10-22_07-23-44_LIBRARY_EVP-AKE31ASW_EVP-AKE3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; 2025-10-22_07-23-44_LIBRARY_SW_EVP-AKE31A_PAN
SW_UP: 2025-10-22_07-23-44_LIBRARY_EVP-AKE31ASW_EVP-AKE3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; 2025-10-22_07-23-44_LIBRARY_SW_EVP-AKE31A_PAN
TP_BAT_GND: HECTOR_WATCH_1_TPTP20R; HECTOR_WATCH_1_TP20R
TP_ON: HECTOR_WATCH_1_TPTP20R; HECTOR_WATCH_1_TP20R
TP_OP: HECTOR_WATCH_1_TPTP20R; HECTOR_WATCH_1_TP20R
TP_VBAT: HECTOR_WATCH_1_TPTP20R; HECTOR_WATCH_1_TP20R
U3: MAX17048G+T10; ESP32_C6_LIBRARY_SON50P200X200X80-9N

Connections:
3V3/1.7D: C34.2, DMG2305UX-7.2 (S), IC2.C2 (VDD), R5.2, R7.2, R8.2, R_PWR_EPD.2
ALERT/1.6C: U3.5 (!ALERT)
D+/1.5D: D3.4 (I/O2_2)
D-/1.5D: D3.6 (I/O1_2)
DN: D3.1 (I/O1_1), J4.A7 (DN1), J4.B7 (DN2)
DP: D3.3 (I/O2_1), J4.A6 (DP1), J4.B6 (DP2)
EPD_3V3: C1-EP-DR.1, DMG2305UX-7.3 (D), EPD_C5.2, J1.15, J1.16, L5.1
EPD_BUSY/1.5D: J1.9
EPD_CS/1.4C: J1.12
EPD_DC/1.5D: J1.11
EPD_RST/1.5D: J1.10
GDR: J1.2, Q3.1 (G), R2_EP_DR.2
GND: C1-EP-DR.2, C27.1, C29.1, C30.1, C31.1, C32.1, C34.1, C42.2, C43.2, D3.2 (GND), D4.1 (K), EPD_C1.1, EPD_C2.1, EPD_C5.1, EPD_C6.1, EPD_C7.1, EPD_C8.1, EPD_C9.1, EPD_C10.1, EPD_C11.1, EPD_C12.1, IC2.B1 (IN/TRIG), IC2.B3 (GND), J1.8, J1.17, J1.MP1, J1.MP2, J4.A1_B12 (GND), J4.A12_B1 (GND), J4.SH1 (SHIELD), J4.SH2 (SHIELD), J4.SH3 (SHIELD), J4.SH4 (SHIELD), R1_USB.1, R2_EP_DR.1, R2_USB.2, R_TYPE_SEL.1, SJ1.1, SW_DN.1, SW_ENT.1, SW_UP.1, TP_BAT_GND.TP, U3.1 (CTG), U3.4 (GND), U3.6 (QSTRT), U3.9 (EP); also elsewhere on the board
HAPTIC_EN/1.4C: IC2.A1 (EN)
MOSI/1.5B: J1.14
unnamed: C32.2, IC2.A2 (REG)
unnamed: C2-EP-DR.2, D5.2 (A), L5.2, Q3.3 (D)
unnamed: C2-EP-DR.1, D2.1 (K), D4.2 (A)
unnamed: EPD_C10.2, J1.22
unnamed: EPD_C2.2, J1.4
unnamed: EPD_C1.2, J1.5
unnamed: R1_EP_DR.1, R_TYPE_SEL.2, SJ1.2
unnamed: J4.B5 (CC2), R2_USB.1
unnamed: J4.A5 (CC1), R1_USB.2
unnamed: EPD_C6.2, J1.18
unnamed: EPD_C7.2, J1.19
unnamed: EPD_C8.2, J1.20
unnamed: EPD_C12.2, J1.24
OUT+: IC2.A3 (OUT+), TP_OP.TP
OUT-: IC2.C3 (OUT-), TP_ON.TP
P0.13/1.5D: C30.2, R5.1, SW_UP.2
P0.14/1.5D: C31.2, R8.1, SW_ENT.2
P1.01/1.6C: DMG2305UX-7.1 (G), R_PWR_EPD.1
P1.02/1.6C: C29.2, R7.1, SW_DN.2
PREVGH: D5.1 (K), EPD_C9.2, J1.21
PREVGL: D2.2 (A), EPD_C11.2, J1.23
RESE: J1.3, Q3.2 (S), R1_EP_DR.2
SCK/1.5B: J1.13
SCL/1.4C: IC2.C1 (SCL), U3.7 (SCL)
SDA/1.4C: IC2.B2 (SDA), U3.8 (SDA)
VBAT/1.2A: C27.2, TP_VBAT.TP, U3.2 (CELL), U3.3 (VDD)
VBUS/1.5D: C42.1, C43.1, D3.5 (VBUS), J4.A4_B9 (VBUS), J4.A9_B4 (VBUS)

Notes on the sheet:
E-Paper Drive Circuit
E-Paper Display Connector
Haptic Driver
Fuel Gauge
Buttons
USB C Connector & ESD Protection

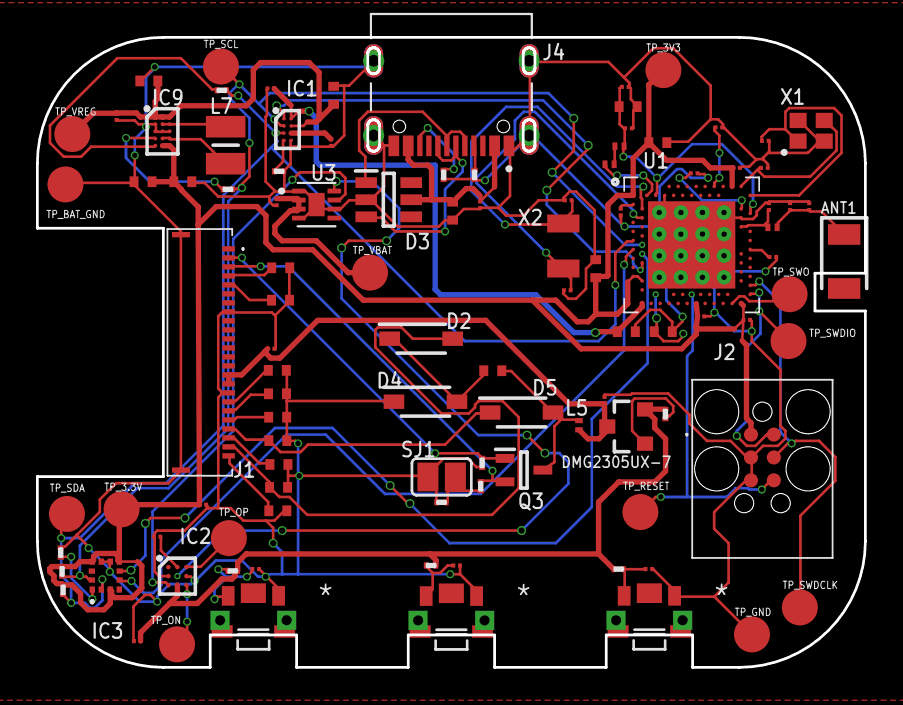
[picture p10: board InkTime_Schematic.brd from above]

Board: 2 copper layers, 46.0 x 35.0 mm, 105 parts (0 on the bottom side), 65 nets.

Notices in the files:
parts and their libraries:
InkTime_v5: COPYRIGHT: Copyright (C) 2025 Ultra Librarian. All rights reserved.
